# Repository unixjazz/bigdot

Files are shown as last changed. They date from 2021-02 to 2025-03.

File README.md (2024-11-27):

# librelab::Big Dot

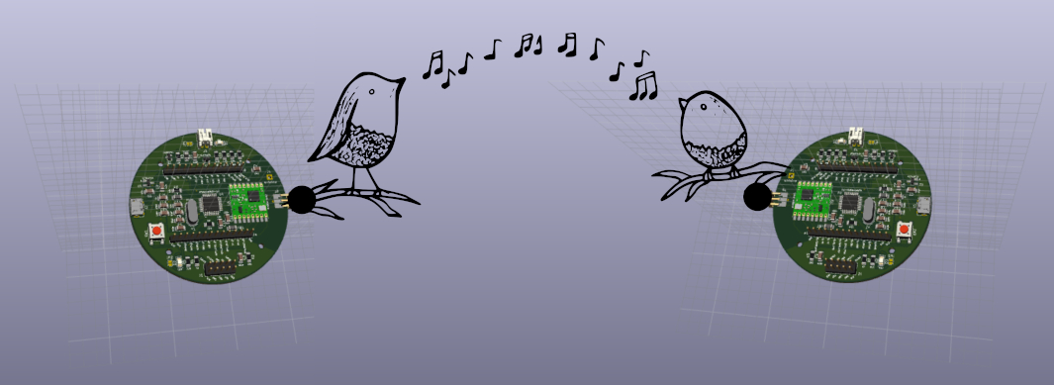
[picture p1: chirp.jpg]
These birds are chirping (CSS) with LoRa!


> A SAML21-based board kit for your environmental sensing projects!

## Description

In this repository you will find the design and firmware files for librelab::Big Dot, our libre hardware kit for low-energy LoRa applications. The content in this repo is organized in the following way:

```bash
├── arduino-core (support files)
├── board (main board design)
├── board-ext (extension board design)
├── bootloader (firmware files)
├── docs (user documentation)
└── examples (applications)
```

## Installation

### Arduino support

To install the support files for librelab::Big Dot on Arduino, just include the following line in the field 'Additional Boards Manager URL' (under 'Preferences' menu) of your Arduino IDE:

```
https://unixjazz.org/pub/software/package_librelab_index.json
```

We are using the Arduino SAMD core (v1.6), but forked and modified by [MattairTech to add support for the chip SAML21](https://github.com/mattairtech/ArduinoCore-samd). You will need Arduino 1.8.13 or superior to use this core with our board.

This core has been tested on Linux (64-bit), Windows 10, and Mac OS 10.15 (64-bit only). If you need further instructions on how to install the Arduino core, [follow this link](https://www.arduino.cc/en/guide/cores).

### RIOT-OS support

If Arduino is not suitable for your project, you can use better alternatives. All the paths lead to the same destination (when it comes to our finitude as species), but some are more direct than others. You may want to use RIOT-OS! [Our board is supported and the support can be found here](https://github.com/unixjazz/RIOT).

To use RIOT-OS with librelab::Big Dot, just pass its name to `make`:

```bash
$ BOARD=bigdot make all
```

If you are new to RIOT-OS, make sure to follow the [tutorials](https://github.com/RIOT-OS/Tutorials).

## Prototyping

If you do not have a Big Dot at hand, you can use a SAML21 Xplained board for testing purposes. The information on how to flash the bootloader we use can be found in the [bootloader directory](bootloader/README.md). For your convenience, we also included pre-compiled firmware files in this repository as well.

We recommend the usage of the UF2 bootloader included in the `bootloaders` directory: `bigdot-uf2.bin`.

## Project info

Big Dot was developed at librelab, School of Data Science (UVA) with funding from the "Network Public Spaces" (NPS) project between 2020-2021. Since then, it has been run as an independent project by Open Hardware enthusiasts.

## License

All the documentation is released as CC-BY-4.0-International.
All the hardware code is released under CERN-OHL-v2 Strongly Reciprocal.
All software code is released under GPL v3, unless marked otherwise on the source file headers. See LICENSE and AUTHORS files for further information.

Big Dot is Open Source Hardware-certified.

big-dot-cert-oshw

__Happy hw hacking!__

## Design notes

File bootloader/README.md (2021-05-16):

# SAML21 Prototyping Notes

In this document, we describe the steps for setting up the SAML21 Xplained Pro dev board for testing purposes.

## Bootloader Installation

We must use a set of tools for writing the bootloader and firmware files to the SAML21 for prototyping purposes. Here are the steps to get it up and running:

**Dependencies**

- OpenOCD v.0.10.0 or superior
- [GCC-arm-none-eabi-7-2017-q4-major](https://developer.arm.com/tools-and-software/open-source-software/developer-tools/gnu-toolchain/gnu-rm/downloads) (this is also included in the Arduino SAMD core with support for Big Dot, installable through the Arduino IDE "Boards Manager")
- [BOSSA](https://github.com/shumatech/BOSSA/releases)
- Debian 10 (or any other distro) w/ extra packages: 'libwxgtk3.0-dev' and 'libreadline-dev'

### Building the Bootloader

*Note: there are precompiled binaries included in the `bootloader` directory*

We need to build the bootloader for our board and our specific target MCU. Change to the directory `bootloader/ArduinoCore-samd-1.6.18-beta-b1/bootloaders/zero` and type:

```
$ BOARD_ID=XPLAINED_SAML21 MCU=SAML21J18B make all mostly_clean
```

After a few moments, you will have the bootloader (8K) with USB terminal support ready in the file `sam_ba_XPLAINED_SAML21_SAML21J18B.bin`.

## Bootloader alternatives

For your convenience, we built 3 different bootloaders:

* 'bigdot.bin': the standard arduino bootloader for the SAM platform
* 'bigdot-uf2.bin': the UF2 alternative bootloader w/ USB mass storage support (our choice!)
* 'sam_ba_XPLAINED_SAML21_SAML21J18B.bin': the standard arduino bootloader for the XPLAINED_SAML21 board 

Our example below uses the bootloader for the XPLAINED dev board, but you should use the 'bigdot' alternatives above if you are prototyping with librelab::Big Dot. All the bootloader files mentioned above can be found under the directory 'bootloaders'.

### Runing OpenOCD

#### Using Atmel EDBG

Plug the USB cable on the 'debug USB' port and run OpenOCD w/ the configuration file included in the `openocd-conf` directory.

```
$ openocd -f openocd-SAML21.cfg
```
If everything goes as planned, you will see this output:

```
cortex_m reset_config sysresetreq
Info : CMSIS-DAP: SWD  Supported
Info : CMSIS-DAP: Interface Initialised (SWD)
Info : CMSIS-DAP: FW Version = 03.25.01B6
Info : SWCLK/TCK = 1 SWDIO/TMS = 1 TDI = 1 TDO = 1 nTRST = 0 nRESET = 1
Info : CMSIS-DAP: Interface ready
Info : clock speed 400 kHz
Info : SWD DPIDR 0x0bc11477
Info : at91saml21j18.cpu: hardware has 4 breakpoints, 2 watchpoints
```

Do not close this terminal or exit out of OpenOCD for the next steps. 

#### Using ATMEL-ICE

If you are privileged enough to have an ATMEL ICE programmer, you can use it to program the bootloader on a brand new chip. 

Please note that you can also use any STM32F103 that you might have laying around... 
In any case, here is how to do it with the super expensive programmer!

First, ensure the 'target chip' is set properly to match your chip in the `openocd-ATMEL-ICE.cfg` file.

```T
# target chip
set CHIPNAME at91saml21j18
source [find target/at91samdXX.cfg]
```

 Plug your programmer's SAM port to the "Cortex Debug" header of your board. Then, power your board via the target USB port with and run:

```
$ openocd -f openocd-ATMEL-ICE.cfg
```

This is the output you will see on your console:

```
Info : Listening on port 6666 for tcl connections
Info : Listening on port 4444 for telnet connections
Info : CMSIS-DAP: SWD  Supported
Info : CMSIS-DAP: JTAG Supported
Info : CMSIS-DAP: FW Version = 01.00.0021
Info : CMSIS-DAP: Serial# = J42700024764
Info : CMSIS-DAP: Interface Initialised (SWD)
Info : SWCLK/TCK = 1 SWDIO/TMS = 1 TDI = 1 TDO = 1 nTRST = 0 nRESET = 1
Info : CMSIS-DAP: Interface ready
Info : clock speed 400 kHz
Info : SWD DPIDR 0x0bc11477
Info : at91saml21j18.cpu: hardware has 4 breakpoints, 2 watchpoints
Info : starting gdb server for at91saml21j18.cpu on 3333
Info : Listening on port 3333 for gdb connections
```

Do not close this terminal or exit out of OpenOCD for the next steps.

### Write Bootloader

If you are dealing with a new chip, you will have to write the bootloader and set the fuses to protect it w/ OpenOCD. First connect to the chip:

```
$ telnet 0 4444 
```
Now you can write the bootloader:

```
reset halt
at91samd bootloader 0
program sam_ba_Generic_x21J_SAML21J18B.bin verify
at91samd bootloader 8192	# this command is optional, recommended to prevent BOSSA from erasing bootloader
reset
shutdown
```
The precompiled bootloader image for the SAML21J18B was obtained from the Mattair's repository. You can find more information on how to compile the bootloader image from the documentation of his fork.

If everything goes well, you are now ready to write your programs using the Arduino core framework to the target (SAML21). This is the output of a successful verification:

```
** Programming Started **
auto erase enabled
Info : SAMD MCU: SAML21J18B (256KB Flash, 32KB RAM)
wrote 16384 bytes from file /home/unixjazz/code/SAML21-xplained-board/bootloader-arduino/sam_ba_Generic_x21J_SAML21J18B.bin in 3.540651s (4.519 KiB/s)
** Programming Finished **
** Verify Started **
verified 4964 bytes in 0.181510s (26.707 KiB/s)
** Verified OK **
** Resetting Target **
```

You should verify if everything is fine by checking if the board is properly enumerated by running

```
# dmesg
```

This should return the following output:

```
usb 3-1.2: New USB device found, idVendor=0000, idProduct=0000, bcdDevice= 2.00
usb 3-1.2: New USB device strings: Mfr=1, Product=2, SerialNumber=0
cdc_acm 3-1.2:1.0: ttyACM0: USB ACM device
```

Voilà! Toolchain and programmer are now ready for embedded fun to start.

### Flash Your Firmware

You are now ready to upload an Arduino sketch (such as `usb-term-test.bin` under the `sketches` directory) to test the USB terminal.

If you plug your board using the 'target USB' port, it should enumerate and you should have access to it. Now, you can use any tool to program your device using the USB port. You can use any sketch that makes use of USB output to test.

## Using BOSSA

Once you have the bootloader installed, you can use the `bossa` GUI utility or the `bossac` command-line utility to flash firmware onto the chip.

### Compile BOSSA

Just run `make` and `make install` to get it all ready. The binaries will be on the folder 'bin/' (`bossa`: GUI, and `bossac`: command-line tool).

### Flashing the Sample Firmware

First, test that the bootloader is successfully installed by attempting to flash the demo firmware:

```
$ bossac -e -w -v -o 8192 -b usb-term-test.bin
```

If it is successful, then you should get the following message:

```
Erase flash

Done in 0.901 seconds
Write 11856 bytes to flash (186 pages)
[==============================] 100% (186/186 pages)
Done in 0.068 seconds
Verify 11856 bytes of flash
[==============================] 100% (186/186 pages)
Verify successful
Done in 0.096 seconds
Set boot flash true
```

If you get the message

```
Device unsupported
```

and the device is properly enumerated, then press the reset button twice to enter bootloader mode.

To test to see if the sample firmware is working correctly, first open a terminal and run:

```
$ screen /dev/ttyACM0
```

Or use your favorite serial monitor, which we assume is 'screen'.

__Happy hw hacking!__

-- Sign-off: LFRM, 02/18/2021

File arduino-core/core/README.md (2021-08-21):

# librelab::Big Dot

Big Dot is a SAML21-based board targeted for low-power applications. It
was designed as an SMD kit, meant to be soldered by hand with a small
number of components.

For more information, see LICENSE and AUTHORS in the `board/` directory.
Credits for this Arduino core and its SAML21 extensions are described
below.
 
## License and Credits

This core has been developed by Arduino LLC in collaboration with Atmel.
The support for SAML21 was developed by Justin Mattair of MattairTech LLC.

```
  Copyright (c) 2015 Arduino LLC.  All right reserved.
  Copyright (c) 2017-2018 MattairTech LLC. All right reserved.

  This library is free software; you can redistribute it and/or
  modify it under the terms of the GNU Lesser General Public
  License as published by the Free Software Foundation; either
  version 2.1 of the License, or (at your option) any later version.

  This library is distributed in the hope that it will be useful,
  but WITHOUT ANY WARRANTY; without even the implied warranty of
  MERCHANTABILITY or FITNESS FOR A PARTICULAR PURPOSE.
  See the GNU Lesser General Public License for more details.

  You should have received a copy of the GNU Lesser General Public
  License along with this library; if not, write to the Free Software
  Foundation, Inc., 51 Franklin St, Fifth Floor, Boston, MA  02110-1301  USA

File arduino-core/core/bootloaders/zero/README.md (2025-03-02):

# Arduino Zero Bootloader

This bootloader is based on the Arduino Zero bootloader, which is a part of the Arduino SAMD core. This version has support for the SAML21 microcontroller, written by Justin Mattair.

## Features

* SAM-BA USB CDC and UART interfaces with optional terminal mode
* Arduino IDE auto-reset and double-tap reset button support
* Arduino extended commands for faster firmware loading
* Bossac command line utility for Linux and OS X

## License

Copyright (c) 2015 Arduino LLC.  All right reserved.
Copyright (c) 2015 Atmel Corporation/Thibaut VIARD.  All right reserved.
Copyright (c) 2017 MattairTech LLC. All right reserved.

This library is free software; you can redistribute it and/or
modify it under the terms of the GNU Lesser General Public
License as published by the Free Software Foundation; either
version 2.1 of the License, or (at your option) any later version.

This library is distributed in the hope that it will be useful,
but WITHOUT ANY WARRANTY; without even the implied warranty of
MERCHANTABILITY or FITNESS FOR A PARTICULAR PURPOSE.
See the GNU Lesser General Public License for more details.

You should have received a copy of the GNU Lesser General Public
License along with this library; if not, write to the Free Software
Foundation, Inc., 51 Franklin St, Fifth Floor, Boston, MA  02110-1301  USA

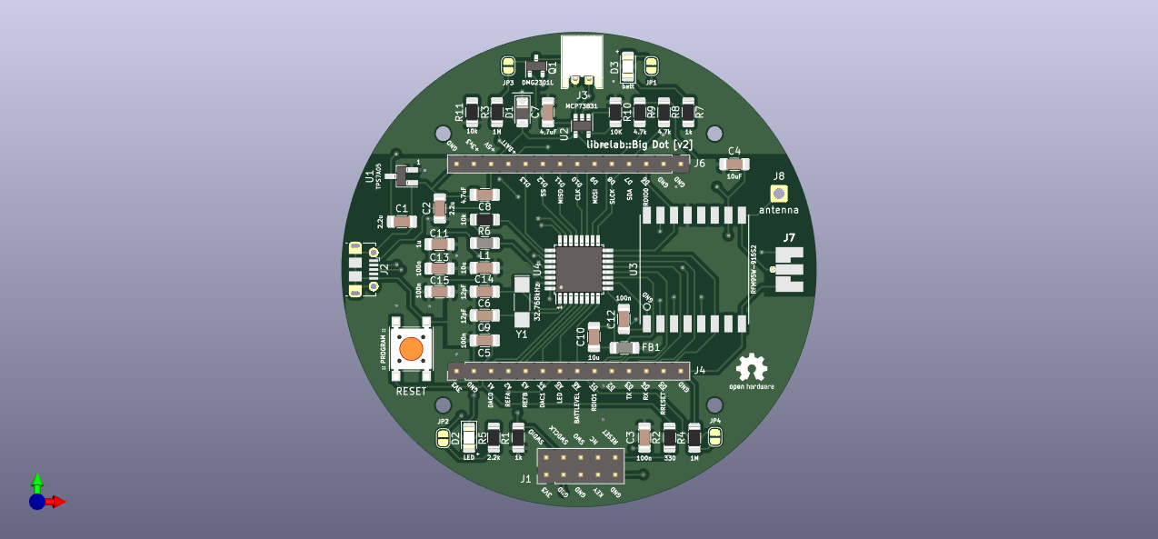
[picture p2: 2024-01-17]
board/bigdot.png

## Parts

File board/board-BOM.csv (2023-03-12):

Source: | /home/unixjazz/code/hardware/bigdot/board/board.sch |  |  |  | TPS7A0533PDBZR | TPS7A0533PDBZR
Date: | Sat 03 Jul 2021 04:25:41 PM EDT
Tool: | Eeschema 5.1.9+dfsg1-1~bpo10+1
Generator: | /usr/share/kicad/plugins/bom_csv_grouped_by_value.py
Components total | 44
SMD pads total | 146
SMD pads front | 141
SMD pads back | 5
TH pads | 45
Item | Qty | Reference(s) | Value | Datasheet | Description | Manufacturer_part_number
1 | 3 | C1, C10, C14 | 10u | ~ | CAP CER 10UF 10V X7R 1206 | C1206C106K8RAC7210
2 | 1 | C2 | 2.2u | ~ | CAP CER 2.2UF 10V X7R 1206 | C1206C225K8RACAUTO
3 | 5 | C3, C5, C12, C13, C15 | 100n | ~ | CAP CER 0.1UF 10V X7R 1206 | C1206C104K8RAC7800
4 | 3 | C4, C7, C8 | 10uF | ~ | CAP CER 10UF 10V X7R 1206 | C1206C106K8RAC7210
5 | 2 | C6, C9 | 12pF NPO | ~ | CAP CER 12PF 50V C0G/NPO 1206 | CC1206JRNPO9BN120
6 | 1 | C11 | 1u | ~ | CAP CER 1UF 10V X7R 1206 | C1206C105K8RAC7800
7 | 1 | D1 | D_Schottky | https://www.diodes.com/assets/Datasheets/ds13002.pdf | DIODE SCHOTTKY 20V 1A SOD123FL | MBR120VLSFT3GOSCT-ND
8 | 1 | D2 | LED | ~ | GREEN LED 1206 SMD
 | 1 | D3 | LED | ~ | RED LED 1206 SMD
9 | 1 | FB1 | FBMH3216HM221NT | https://ds.yuden.co.jp/TYCOMPAS/ut/detail?pn=FBMH3216HM221NT%20&u=M | FERRITE BEAD 220 OHM 1206 1LN | FBMH3216HM221NT
10 | 1 | J1 | Conn_ARM_JTAG_SWD_10 | https://media.digikey.com/pdf/Data%20Sheets/Sullins%20PDFs/Female_Headers.100_DS.pdf | Conn_ARM_JTAG_SWD_10 | PPPC052LFBN-RC
11 | 1 | J2 | USB_B_Micro | https://www.hirose.com/product/document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 | CONN RCPT USB2.0 MICRO B SMD R/A | ZX62D-B-5P8(30)
12 | 1 | J3 | Conn_01x02 | https://www.jst-mfg.com/product/pdf/eng/ePH.pdf | CONN HEADER R/A 2POS 2MM | S2B-PH-K-S(LF)(SN)
13 | 1 | J4 | Conn_01x14 | ~ | CONN HEADER 14POS -.100” [2.54 mm] Contact Centers, Female Headers,Straight/Right Angle/SMT
14 | 1 | J6 | Conn_01x14 | ~ | CONN HEADER 14POS -.100” [2.54 mm] Contact Centers, Female Headers,Straight/Right Angle/SMT
15 | 1 | J7 | Conn_Coaxial | https://www.digikey.com/en/products/detail/samtec-inc/SMA-J-P-H-ST-EM1/2602450 | CONN SMA JACK STR 50OHM EDGE MNT | SMA-J-P-H-ST-EM1
19 | 1 | L1 | 10u | https://katalog.we-online.com/pbs/datasheet/7447918.pdf | FIXED IND 10UH 25MA 600 MOHM SMD | 7447918
20 | 1 | Q1 | DMG2301L | https://www.diodes.com/assets/Datasheets/DMG2301L.pdf | MOSFET P-CH 20V 2.4A SOT23 | DMG2301LK-7
21 | 2 | R1, R7 | 1k | ~ | RES 1K OHM 1% 1/4W 1206 | RMCF1206FT1K00
22 | 1 | R2 | 330 | ~ | RES 330 OHM 1% 1/4W 1206 | RMCF1206FT330R
23 | 2 | R3, R4 | 1M | ~ | RES 1M OHM 1% 1/4W 1206 | CR1206-FX-1004ELF
24 | 1 | R5 | 2.2k | ~ | RES 2.2K OHM 1% 1/4W 1206 | RMCF1206FT2K20
25 | 2 | R6, R11 | 10k | ~ | RES 10K OHM 1% 1/4W 1206 | RMCF1206FT10K0
26 | 2 | R8, R9 | 4.7k | ~ | RES 4.7K OHM 1% 1/4W 1206 | CRG1206F4K7
27 | 1 | R10 | 2.0K | ~ | RES 2K OHM 1% 1/4W 1206 | RMCF1206FT2K00
28 | 1 | SW1 | SW_Push | https://www.ckswitches.com/media/1471/pts645.pdf | SWITCH TACTILE SPST-NO 0.05A 12V | PTS645SL50SMTR92 LFS
29 | 1 | U1 | TPS7A05 | https://www.ti.com/lit/ds/symlink/tps7a05.pdf | TPS7A0533PDBZR | TPS7A0533PDBZR
30 | 1 | U2 | MCP73831T-2ACI/OT | http://ww1.microchip.com/downloads/en/DeviceDoc/20001984g.pdf | IC BATT CNTL LI-ION 1CEL SOT23-5 | MCP73831T-2ACI/OT
31 | 1 | U3 | RFM95W-915S2 | http://www.hoperf.com/upload/rf/RFM95_96_97_98W.pdf
32 | 1 | U4 | ATSAML21E18B-AUT | http://ww1.microchip.com/downloads/en/DeviceDoc/SAM_L21_Family_DataSheet_DS60001477C.pdf | IC MCU 32BIT 256KB FLASH 32TQFP | ATSAML21E18B-AUT
33 | 1 | Y1 | 32.768kHz | https://abracon.com/Resonators/ABS10.pdf | CRYSTAL 32.7680KHZ 9PF SMD | ABS10-32.768KHZ-9-T

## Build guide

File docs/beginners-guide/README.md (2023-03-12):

# Getting Started With Arduino

**You must add the URL from the 'Arduino support section' before proceeding**

Open Arduino IDE->Tool->Board and click on Board Manager. In the search bar, type "Big Dot" then download "librelab::Big Dot by UVA SDS". Now that you have the board downloaded, to select the board go to Tools->Board->librelab::Big Dot and select Big Dot. Now Select the port, Tools->Port->(Select the port that says BigDot, i.e., "COM3 BigDot").
Now you've downloaded and selected the Big Dot!
Don't forget about the port!

**You must add the URL from the Arduino support section before you begin this section**

## Hello World!

In your Arduino IDE, select File->Examples->01.Basics and click on Blink. To upload code to BigDot, you must first press the RESET button twice. You'll know you're ready to upload code when the LED is pulsing. Once the LED is pulsing from pressing the reset button twice, click on the upload button (Arrow pointing to the right). Congrats! You should see the LED turn on and off every second.
## Required Libraries
Please download the zip files below
1. [SparkfunBME280](https://github.com/Wesleylewis05/SparkFun_BME280_Arduino_Library)
2. [U8g2lib](https://github.com/Wesleylewis05/U8g2_Arduino)
3. [PMS7003](https://github.com/Wesleylewis05/PMS)
4. [Lmic](https://github.com/Wesleylewis05/arduino-lmic)
5. [ArduinoLowPower](https://github.com/Wesleylewis05/ArduinoLowPower)
7. [RTCZero](https://github.com/Wesleylewis05/RTCZero)
7. [Adafruit Neopixel](https://github.com/Wesleylewis05/Adafruit_NeoPixel)
8. [Sam32wifiesp](https://github.com/Wesleylewis05/SAM32WiFiEsp)
9. [PubSubClient](https://github.com/Wesleylewis05/pubsubclient)
10. [AdafruitMQTT](https://github.com/Wesleylewis05/Adafruit_MQTT_Library)

Once you've downloaded everything uploads the files in your IDE. In order to use the libraries you'll have to download the zip and open Arduino IDE->Sketch->Include Library->Add .ZIP Library.

Now you're all set for using the board!

# Uploading UF2

Once you have downloaded or cloned the repository, open the "uf2_examples" directory. You should see a file named LEDPM.UF2. Now reset the board by pressing the RESET button twice. You'll know the board is reset once you see the LED next to the reset button pulse. After you've reset the board, you'll now be able to drag LEDPM.UF2 into the BigDot folder.
UF2_visualize

# Using the AdafruitIO Dashboard

To display the information from the BigDot, I will teach you how to get started using the free version of AdafruitIO. You can read more about the dashboard [here](https://io.adafruit.com/). For this, you'll need a Wifi extension board, so if you don't have that, you'll have to make some changes to the code we provide, as an example. In this tutorial, I will go over how to get started. For more information, use this [link](https://learn.adafruit.com/welcome-to-adafruit-io).

1. Create an account with Adafruit [here](https://accounts.adafruit.com/users/sign_up).

2. Go to https://io.adafruit.com/ and you should see something like below

<p align="center">
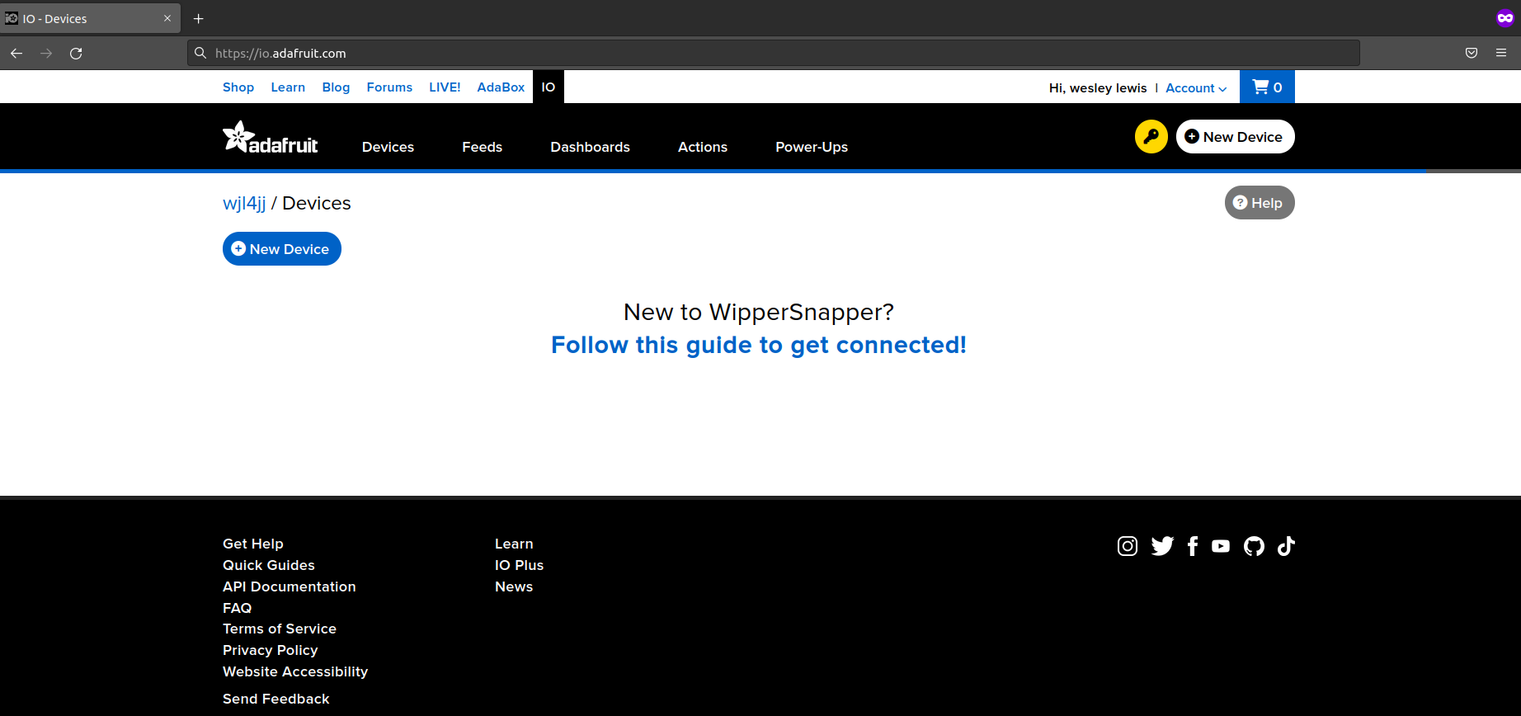
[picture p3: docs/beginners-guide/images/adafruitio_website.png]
adafruitio_website

</p>

3. Click on "Dashboards" then click on "New Dashboard" and give it a name and description. (For this example I'm going to name it "PM2_5") You should see something like the below image. If you do click on your new dashboard

<p align="center">
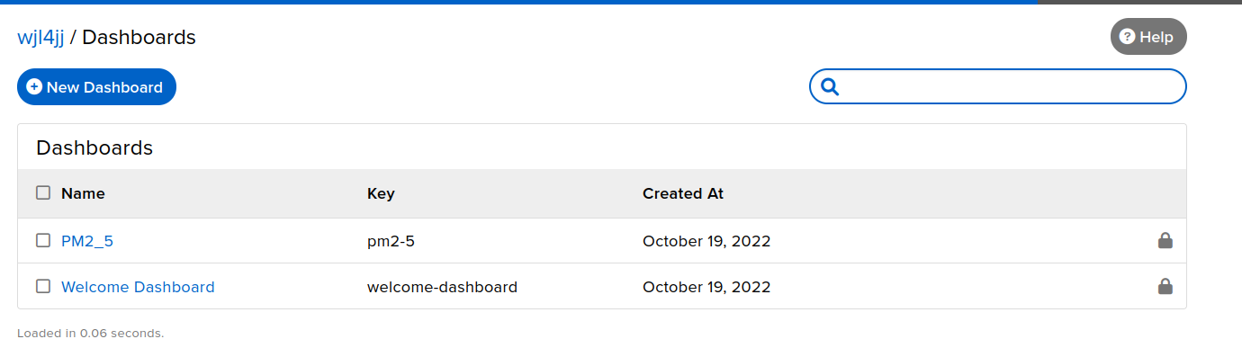
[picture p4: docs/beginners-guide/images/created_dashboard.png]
created_dashboard

</p>

4. Click on the gear icon in the upper right corner and click on "Create New Block", then click on "Line Chart"

5. Enter a feed name (I'm using "PM2_5"). Then click on create **you might have to hover your mouse right of the text box to see the create button.** Now select your new feed and click "Next Step." You can copy the settings I used in the image below.

<p align="center">
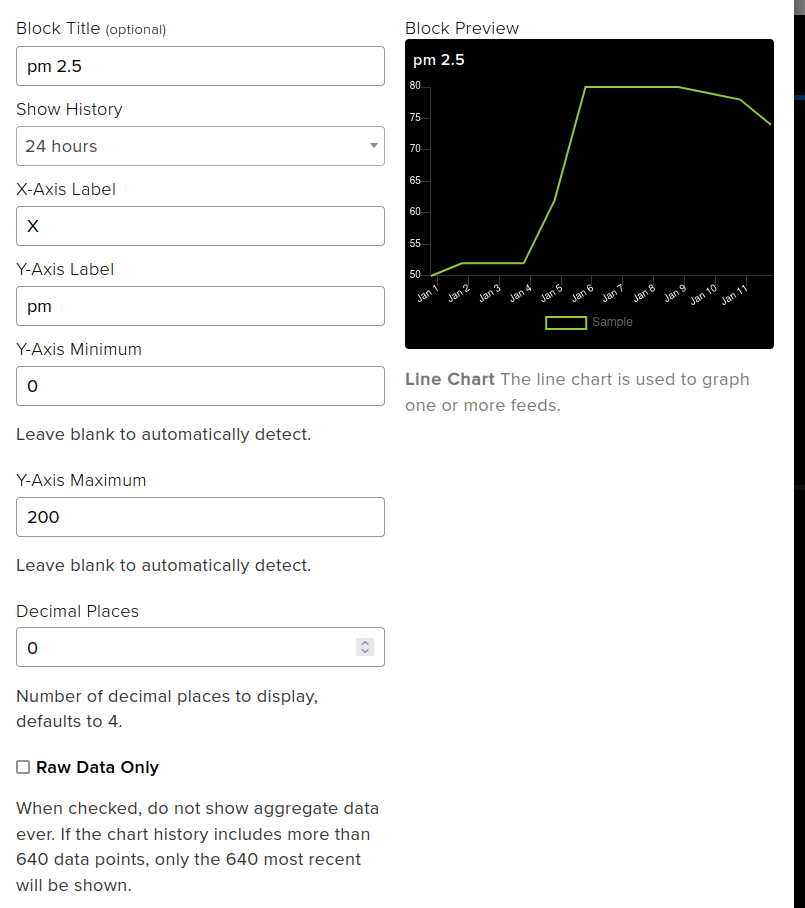
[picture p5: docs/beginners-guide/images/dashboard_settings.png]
dashboard_settings

</p>

6. Once you're finished click on the yellow key in the upper right corner and copy that username and active key somewhere. **You'll need it later.**

<p align="center">
yellow_key
</p>

<p align="center">
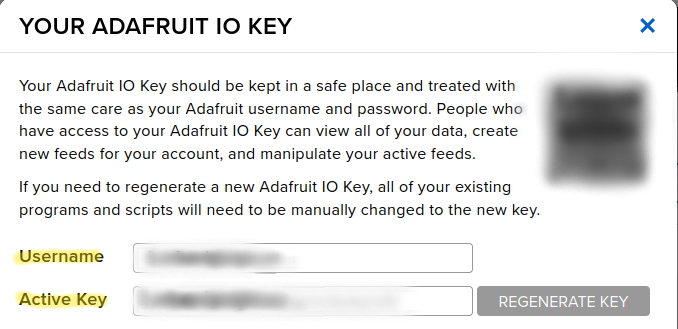
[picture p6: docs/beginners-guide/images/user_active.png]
user_active

</p>

7. Now open up the pms-wifi example from the repository using Arduino. Once it's open, scroll down until you see the Feeds section. Replace the word "TEMP" with your feed name. In this example since I'm using the feed named "PM2_5" I'll replace that with such.

<p align="center">
example_replaced_temp
</p>

8. Go to private_settings.h and replace AIO_USERNAME with the username you just copied down and AIO_KEY with the active key you copied down. Then change the WLAN_SSID name to the name of your network and WLAN_PASS to the password of the network you want to use.

9. You should now be able to upload the code! Congrats!

**Don't forget to reset the board and select the correct port!**

<p align="center">
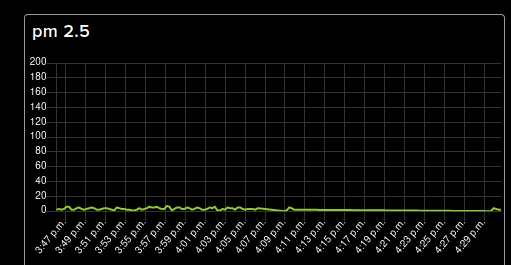
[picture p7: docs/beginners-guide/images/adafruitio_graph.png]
adafruitio_graph

</p>

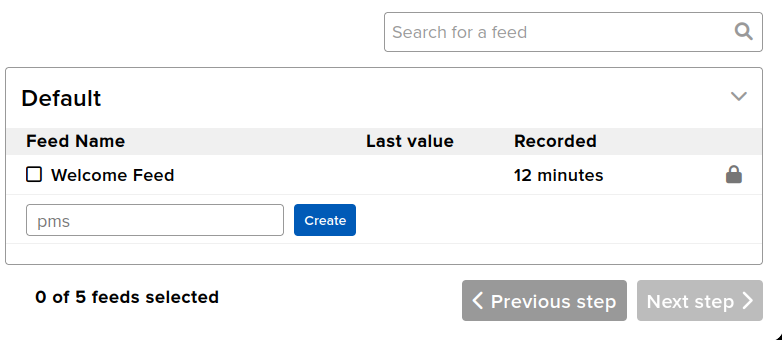
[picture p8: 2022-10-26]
docs/beginners-guide/images/new_feed.png

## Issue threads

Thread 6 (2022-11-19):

add GND plane on the extension board

unixjazz, 2022-11-19:
Hi,

The extension board was made in a rush... it does not contain a GND plane.
Turns out, that is slower and less environmentally friendly to fabricate!

So, this issue is a request for us to add a GND to the extension board and release a new PCB version.

Closed 2023-03-12.

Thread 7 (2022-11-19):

replace LDO on the Big Dot PCB

unixjazz, 2022-11-19:
During the pandemic many parts went out of stock and many got discontinued! Turns out, this is the case of our low power voltage regulator on the Big Dot project.

It is necessary to find a replacement part for U1 and substitute it, releasing a new version of the PCB once it has been tested.

unixjazz, 2022-11-29:
one substitute part would be this new one:
https://ww1.microchip.com/downloads/en/DeviceDoc/MCP1700-Data-Sheet-20001826F.pdf

it is not as energy efficient as the part we originally had, but still...

unixjazz, 2023-03-12:
thank you @Wesleylewis05!  we merged your changes in #11 for v2.

Closed 2023-03-12.

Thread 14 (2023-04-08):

Arduino IDE, v2.0 support

unixjazz, 2023-04-08:
The new version of the Arduino IDE (v2.0) seems to be causing trouble for extension packages for various boards and architectures. This is the case of SAMD (such as Seeed's XIAO) and SAML boards (ours).  We can continue using v1.8.x until Arduino v2.0 is stable, but we must plan for the upgrade soon.

unixjazz, 2023-04-29:
update on this issue:
tested against Arduino IDE v.2.1: custom board package can be installed without problems

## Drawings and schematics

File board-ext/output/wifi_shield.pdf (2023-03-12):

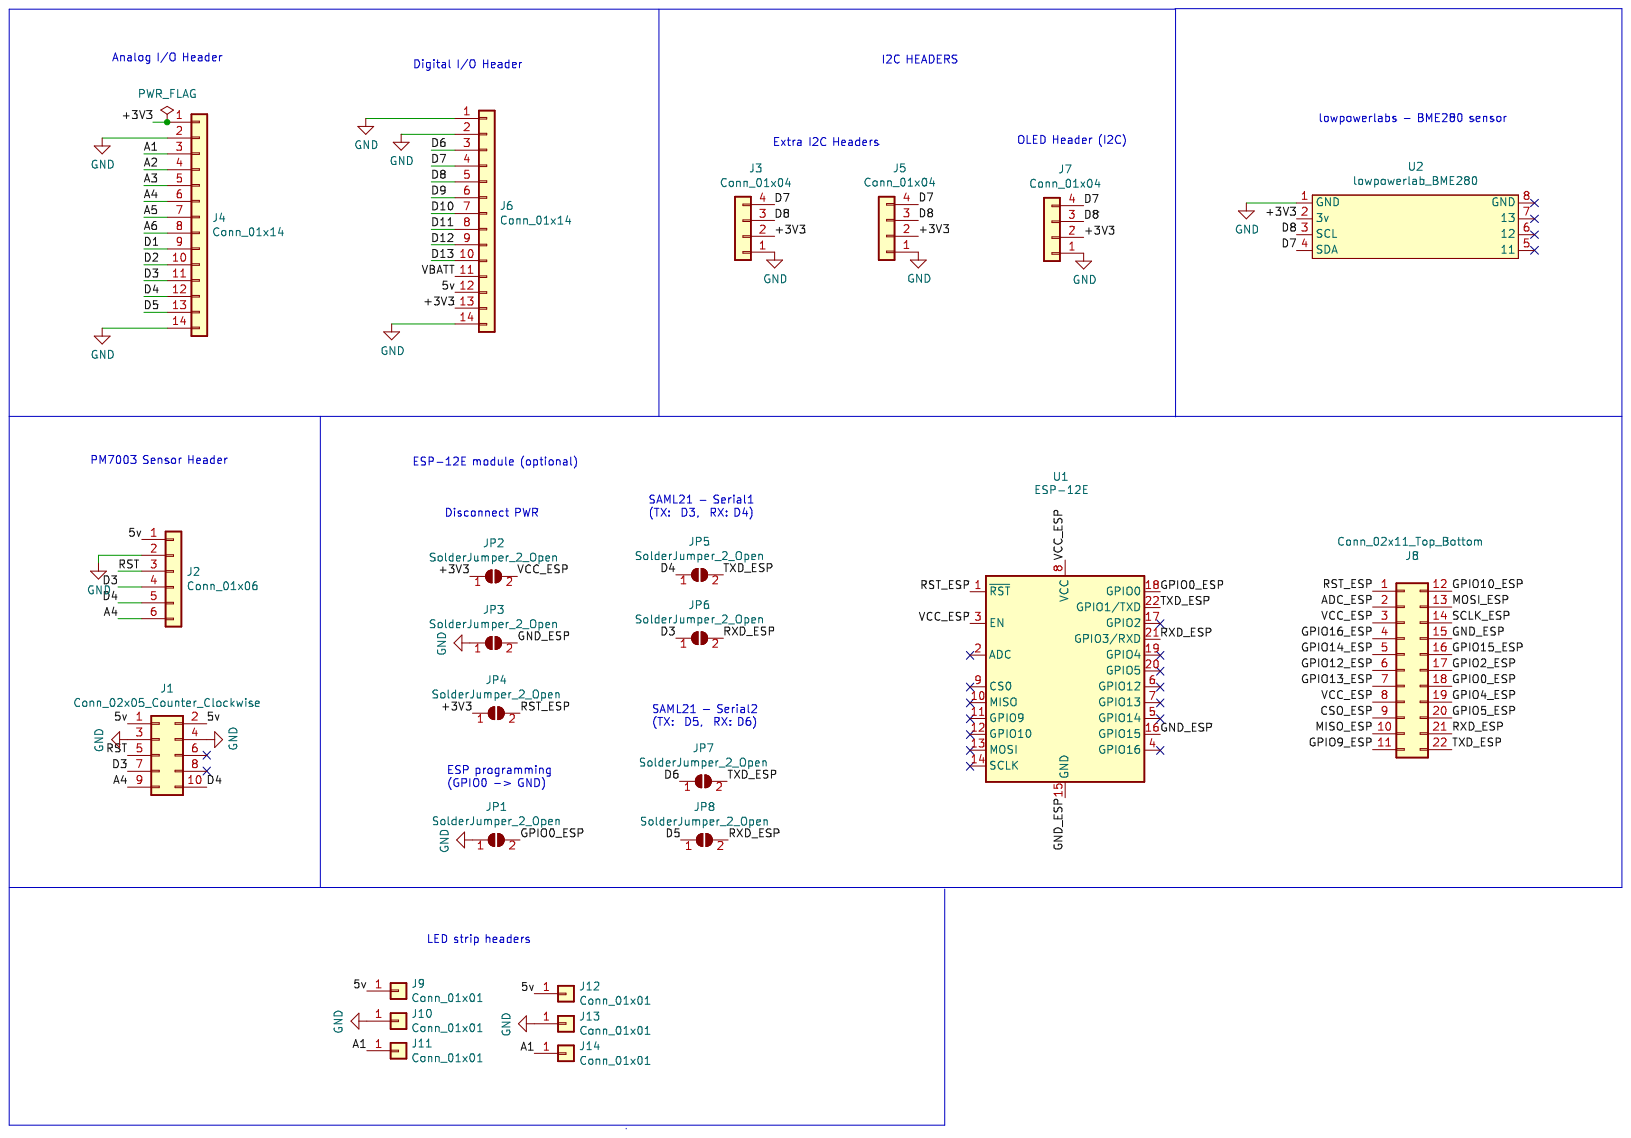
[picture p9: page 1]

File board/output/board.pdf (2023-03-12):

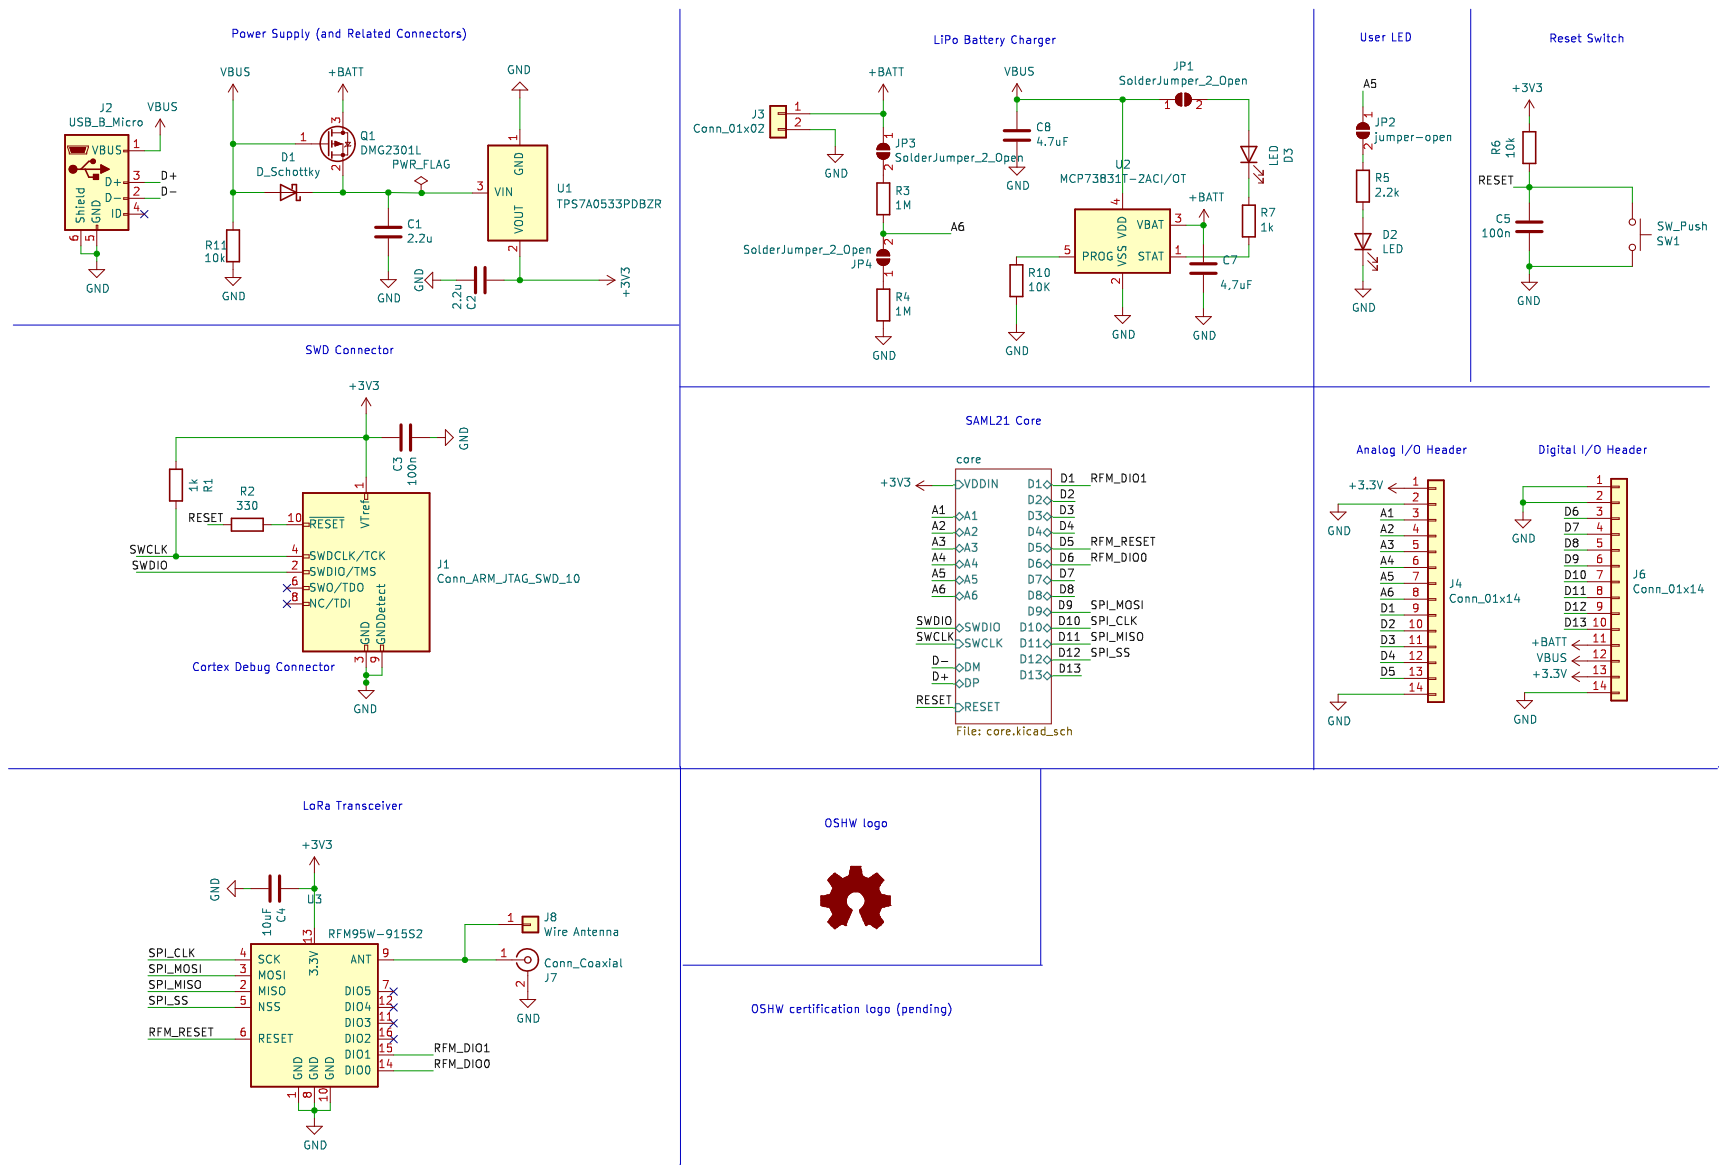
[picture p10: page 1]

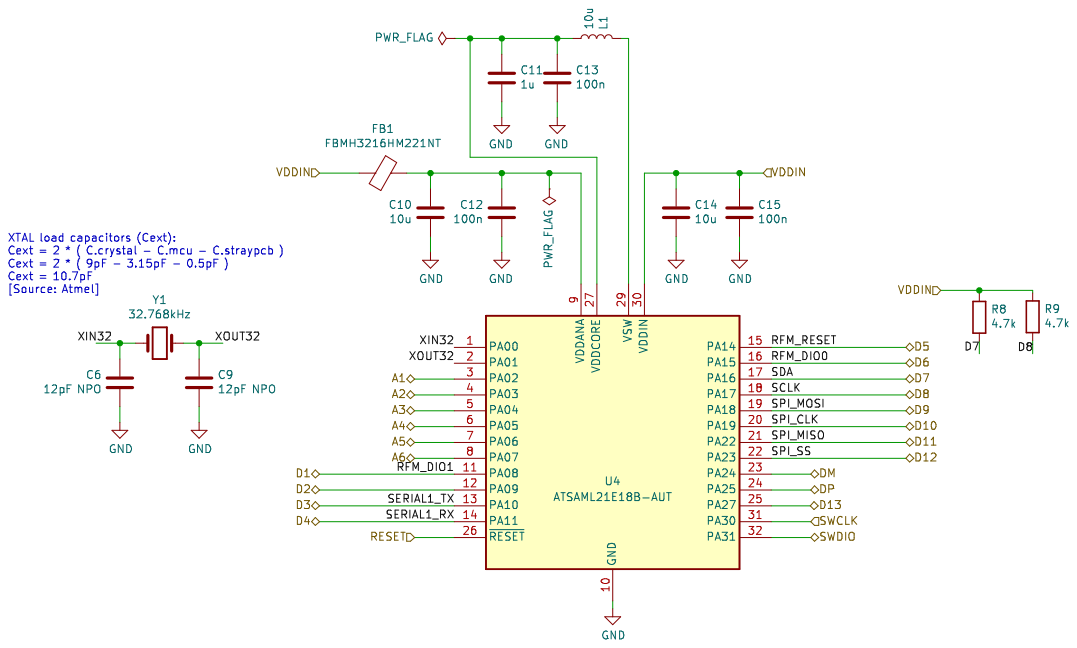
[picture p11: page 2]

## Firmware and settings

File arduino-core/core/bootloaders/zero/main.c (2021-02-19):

/*
  Copyright (c) 2015 Arduino LLC.  All right reserved.
  Copyright (c) 2015 Atmel Corporation/Thibaut VIARD.  All right reserved.

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
  You should have received a copy of the GNU Lesser General Public
  License along with this library; if not, write to the Free Software
  Foundation, Inc., 51 Franklin St, Fifth Floor, Boston, MA  02110-1301  USA
*/

#include <stdio.h>
#include <stdbool.h>
#include <sam.h>
#include "sam_ba_monitor.h"
#include "sam_ba_serial.h"
#include "board_definitions.h"
#include "board_driver_led.h"
#include "util.h"
#if (SAMD21 || SAMD11 || SAML21 || SAMD51)
  #include "sam_ba_usb.h"
  #include "sam_ba_cdc.h"
#endif

extern uint32_t __sketch_vectors_ptr; // Exported value from linker script
extern volatile int8_t ledDirection;
extern void board_init(void);

#if (defined DEBUG) && (DEBUG == 1)
volatile uint32_t* pulSketch_Start_Address;
#endif

static volatile bool main_b_cdc_enable = false;

/**
 * \brief Check the application startup condition
 *
 */
static void check_start_application(void)
{
#if (!defined DEBUG) || ((defined DEBUG) && (DEBUG == 0))
uint32_t* pulSketch_Start_Address;
#endif

  /*
   * Test sketch stack pointer @ &__sketch_vectors_ptr
   * Stay in SAM-BA if value @ (&__sketch_vectors_ptr) == 0xFFFFFFFF (Erased flash cell value)
   */
  if (__sketch_vectors_ptr == 0xFFFFFFFF)
  {
    /* Stay in bootloader */
    return;
  }

  /*
   * Load the sketch Reset Handler address
   * __sketch_vectors_ptr is exported from linker script and point on first 32b word of sketch vector table
   * Remember, variables exported from a linker script are different than normal variables (only address, no value)
   * First 32b word is sketch stack
   * Second 32b word is sketch entry point: Reset_Handler()
   */
  pulSketch_Start_Address = &__sketch_vectors_ptr ;
  pulSketch_Start_Address++ ;

  /*
   * Test vector table address of sketch @ &__sketch_vectors_ptr
   * Stay in SAM-BA if this function is not aligned enough, ie not valid
   */
  if ( ((uint32_t)(&__sketch_vectors_ptr) & ~SCB_VTOR_TBLOFF_Msk) != 0x00)
  {
    /* Stay in bootloader */
    return;
  }

#if defined(BOOT_LOAD_PIN_ENABLED)
  pinConfig(BOOT_LOAD_PIN_PORT, BOOT_LOAD_PIN, BOOT_LOAD_PIN_CONFIG);

  /* Allow time for debouncing capacitor (if using a button) to charge (10ms) */
  delayUs(10000UL);

  // Read the BOOT_LOAD_PIN status
  if (isPinActive(BOOT_LOAD_PIN_PORT, BOOT_LOAD_PIN, BOOT_LOAD_PIN_POLARITY))
  {
    // Stay in bootloader
    return;
  }
#endif

#if defined(BOOT_DOUBLE_TAP_ENABLED)
  #define DOUBLE_TAP_MAGIC 0x07738135

#if (SAMD21 || SAMD11)
  if (PM->RCAUSE.bit.POR)
#elif (SAML21 || SAMC21 || SAMD51)
  if (RSTC->RCAUSE.bit.POR)
#else
  #error "main.c: Missing dependency or unsupported chip. Please install CMSIS-Atmel from MattairTech (see Prerequisites for Building in README.md)."
#endif

  {
    /* On power-on initialize double-tap */
    BOOT_DOUBLE_TAP_DATA = 0;
  }
  else
  {
    if (BOOT_DOUBLE_TAP_DATA == DOUBLE_TAP_MAGIC)
    {
      /* Second tap, stay in bootloader */
      BOOT_DOUBLE_TAP_DATA = 0;
      return;
    }

    /* First tap */
    BOOT_DOUBLE_TAP_DATA = DOUBLE_TAP_MAGIC;

    /* Wait 0.5sec to see if the user tap reset again */
    delayUs(500000UL);

    /* Timeout happened, continue boot... */
    BOOT_DOUBLE_TAP_DATA = 0;
  }
#endif

  /* Rebase the Stack Pointer */
  __set_MSP( (uint32_t)(__sketch_vectors_ptr) );

  /* Rebase the vector table base address */
  SCB->VTOR = ((uint32_t)(&__sketch_vectors_ptr) & SCB_VTOR_TBLOFF_Msk);

  /* Jump to application Reset Handler in the application */
  asm("bx %0"::"r"(*pulSketch_Start_Address));
}

#if DEBUG_ENABLE
#	define DEBUG_PIN_HIGH 	port_pin_set_output_level(BOOT_LED, 1)
#	define DEBUG_PIN_LOW 	port_pin_set_output_level(BOOT_LED, 0)
#else
#	define DEBUG_PIN_HIGH 	do{}while(0)
#	define DEBUG_PIN_LOW 	do{}while(0)
#endif

/**
 *  \brief SAMD21 SAM-BA Main loop.
 *  \return Unused (ANSI-C compatibility).
 */
int main(void)
{
#if SAM_BA_INTERFACE == SAM_BA_USBCDC_ONLY  ||  SAM_BA_INTERFACE == SAM_BA_BOTH_INTERFACES
  P_USB_CDC pCdc;
#endif
  DEBUG_PIN_HIGH;

  /* Jump in application if condition is satisfied */
  check_start_application();

  /* We have determined we should stay in the monitor. */

  /* System initialization */
  board_init();
  __enable_irq();

  /* Initialize LEDs */
  LED_init();
  #if !defined(BOARD_LED_FADE_ENABLED)
  LED_on();
  #endif
  LEDRX_init();
  LEDRX_off();
  LEDTX_init();
  LEDTX_off();

  /* Start the sys tick (20 us) */
  SysTick_Config(VARIANT_MCK / 50000);


/* When using SAM_BA_INTERFACE_USE_PIN, check the pin to determine which SAM-BA interface to use.
 */
#if defined(SAM_BA_INTERFACE_USE_PIN)
  uint8_t sambaInterface = SAM_BA_NONE;
  pinConfig(SAM_BA_INTERFACE_PIN_PORT, SAM_BA_INTERFACE_PIN_PIN, SAM_BA_INTERFACE_PIN_CONFIG);

  if (isPinActive(SAM_BA_INTERFACE_PIN_PORT, SAM_BA_INTERFACE_PIN_PIN, PIN_POLARITY_ACTIVE_LOW)) {      // pin is low
  #if ((SAM_BA_INTERFACE == SAM_BA_BOTH_INTERFACES) && (SAM_BA_INTERFACE_PIN_POLARITY == PIN_POLARITY_USBCDC_LOW))
    sambaInterface = SAM_BA_USBCDC_ONLY;
  #elif ((SAM_BA_INTERFACE == SAM_BA_USBCDC_ONLY) && (SAM_BA_INTERFACE_PIN_POLARITY == PIN_POLARITY_ACTIVE_LOW))
    sambaInterface = SAM_BA_USBCDC_ONLY;
  #elif ((SAM_BA_INTERFACE == SAM_BA_UART_ONLY) && (SAM_BA_INTERFACE_PIN_POLARITY == PIN_POLARITY_ACTIVE_LOW))
    sambaInterface = SAM_BA_UART_ONLY;
  #endif
  } else {      // pin is high
  #if ((SAM_BA_INTERFACE == SAM_BA_BOTH_INTERFACES) && (SAM_BA_INTERFACE_PIN_POLARITY == PIN_POLARITY_USBCDC_HIGH))
    sambaInterface = SAM_BA_USBCDC_ONLY;
  #elif ((SAM_BA_INTERFACE == SAM_BA_USBCDC_ONLY) && (SAM_BA_INTERFACE_PIN_POLARITY == PIN_POLARITY_ACTIVE_HIGH))
    sambaInterface = SAM_BA_USBCDC_ONLY;
  #elif ((SAM_BA_INTERFACE == SAM_BA_UART_ONLY) && (SAM_BA_INTERFACE_PIN_POLARITY == PIN_POLARITY_ACTIVE_HIGH))
    sambaInterface = SAM_BA_UART_ONLY;
  #endif
  }
#endif

/* Check if we should continue with a SAM-BA interface (if compiled and enabled).
 * Only show LED_STATUS_FILE_NOT_FOUND if a SAM-BA interface is not available.
 * LED_STATUS_FILE_NOT_FOUND occurs if there is no SD Card, no FAT16/FAT32
 * filesystem, or no file (UPDATE.BIN or UPDATE2.BIN) in the root directory.
 */
#if defined(SAM_BA_INTERFACE_USE_PIN)
  #if defined(SDCARD_ENABLED)
  if (sambaInterface == SAM_BA_NONE) {
    if (sdcardStatus == SD_BOOTLOADER_FILE_NOT_FOUND) {
      LED_status(LED_STATUS_FILE_NOT_FOUND);
    } else if (sdcardStatus == SD_BOOTLOADER_NOT_CALLED) {
      LED_status(LED_STATUS_NO_SAM_BA_INTERFACE);
    }
  }
  #else
    #if (SAM_BA_INTERFACE == SAM_BA_NONE)
      LED_status(LED_STATUS_NO_SAM_BA_INTERFACE);
    #else
    if (sambaInterface == SAM_BA_NONE) {
      LED_status(LED_STATUS_NO_SAM_BA_INTERFACE);
    }
    #endif
  #endif
#else
  #if (SAM_BA_INTERFACE == SAM_BA_NONE)
    LED_status(LED_STATUS_NO_SAM_BA_INTERFACE);
  #endif
#endif

/* Enable the appropriate SAM-BA interfaces. When using SAM_BA_INTERFACE_USE_PIN,
 * the peripheral and pins are only setup for the selected/enabled interface.
 */
#if defined(SAM_BA_INTERFACE_USE_PIN)
  if (sambaInterface == SAM_BA_UART_ONLY) {
#endif

#if SAM_BA_INTERFACE == SAM_BA_UART_ONLY  ||  SAM_BA_INTERFACE == SAM_BA_BOTH_INTERFACES
  /* UART is enabled in all cases */
    serial_open();
#endif

#if defined(SAM_BA_INTERFACE_USE_PIN)
  } else if (sambaInterface == SAM_BA_USBCDC_ONLY) {
#endif

#if SAM_BA_INTERFACE == SAM_BA_USBCDC_ONLY  ||  SAM_BA_INTERFACE == SAM_BA_BOTH_INTERFACES
    pCdc = usb_init();
#endif

#if defined(SAM_BA_INTERFACE_USE_PIN)
  }
#endif


  ledDirection = 4;
  DEBUG_PIN_LOW;

  /* Wait for a complete enum on usb or a '#' char on serial line */
  while (1)
  {
#if defined(SAM_BA_INTERFACE_USE_PIN)
    if (sambaInterface == SAM_BA_USBCDC_ONLY) {
#endif

#if SAM_BA_INTERFACE == SAM_BA_USBCDC_ONLY  ||  SAM_BA_INTERFACE == SAM_BA_BOTH_INTERFACES
    if (pCdc->IsConfigured(pCdc) != 0)
    {
      main_b_cdc_enable = true;
    }

    /* Check if a USB enumeration has succeeded and if comm port has been opened */
    if (main_b_cdc_enable)
    {
      sam_ba_monitor_init(SAM_BA_INTERFACE_USBCDC);
      /* SAM-BA on USB loop */
      while( 1 )
      {
        sam_ba_monitor_run();
      }
    }
#endif

#if defined(SAM_BA_INTERFACE_USE_PIN)
    } else if (sambaInterface == SAM_BA_UART_ONLY) {
#endif

#if SAM_BA_INTERFACE == SAM_BA_UART_ONLY  ||  SAM_BA_INTERFACE == SAM_BA_BOTH_INTERFACES
    /* Check if a '#' has been received */
    if (!main_b_cdc_enable && serial_sharp_received())
    {
      sam_ba_monitor_init(SAM_BA_INTERFACE_USART);
      /* SAM-BA on Serial loop */
      while(1)
      {
        sam_ba_monitor_run();
      }
    }
#endif

#if defined(SAM_BA_INTERFACE_USE_PIN)
    }
#endif
  }
}

void SysTick_Handler(void)
{
#if (defined(BOARD_LED_FADE_ENABLED) && defined(BOARD_LED_PORT))
  LED_pulse();
#endif

  sam_ba_monitor_sys_tick();
}

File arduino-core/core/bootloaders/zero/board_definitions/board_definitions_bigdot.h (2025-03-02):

/*
  Copyright (c) 2020 Librelab. All right reserved.
  Copyright (c) 2017 MattairTech LLC. All right reserved.
  Copyright (c) 2015 Arduino LLC.  All right reserved.
  Copyright (c) 2015 Atmel Corporation/Thibaut VIARD.  All right reserved.

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
  You should have received a copy of the GNU Lesser General Public
  License along with this library; if not, write to the Free Software
  Foundation, Inc., 51 Franklin St, Fifth Floor, Boston, MA  02110-1301  USA
*/

#ifndef _BOARD_DEFINITIONS_H_
#define _BOARD_DEFINITIONS_H_

#include <sam.h>

/* The SAM-BA interface, which is used with both USB CDC and UART (TTL
 * serial), can operate in either binary (default) or terminal mode. If
 * TERMINAL_MODE_ENABLED is defined, additional terminal handling code
 * (add prompt, add \n\r to EOL, number formatting, etc.) will be compiled
 * in. To switch to terminal mode, type 'T#' (you should then see a prompt).
 * Then, type 'V#' to show version information. See README.md for more commands.
 * Size: ~228B. Enabled by default. Disable with 4KB bootloader.
 */
//#define TERMINAL_MODE_ENABLED

/* Set SAM_BA_INTERFACE to SAM_BA_USBCDC_ONLY, SAM_BA_UART_ONLY, SAM_BA_NONE, or
 * SAM_BA_BOTH_INTERFACES. With 4KB bootloaders, select only one interface (except
 * when using SDCARD_ENABLED, then set SAM_BA_INTERFACE to SAM_BA_NONE).
 */
#define SAM_BA_INTERFACE	SAM_BA_USBCDC_ONLY

/* If ARDUINO_EXTENDED_CAPABILITIES is defined and set to 1, 3 additional commands
 * will become available which will speed up programming when using the Arduino
 * IDE or the bossac tool standalone. Set to 0 with 4KB bootloaders.
 * Size: ~904B. This is defined and set to 1 by default (except with 4KB).
 */
#define ARDUINO_EXTENDED_CAPABILITIES	1

/* The clock source must be chosen by setting CLOCKCONFIG_CLOCK_SOURCE to
 * CLOCKCONFIG_32768HZ_CRYSTAL, CLOCKCONFIG_HS_CRYSTAL, CLOCKCONFIG_INTERNAL,
 * or CLOCKCONFIG_INTERNAL_USB. If CLOCKCONFIG_32768HZ_CRYSTAL or
 * CLOCKCONFIG_HS_CRYSTAL is defined, then the PLL will be used. If
 * CLOCKCONFIG_HS_CRYSTAL is defined, then HS_CRYSTAL_FREQUENCY_HERTZ must
 * also be defined with the crystal frequency in Hertz. CLOCKCONFIG_INTERNAL
 * uses the DFLL in open-loop mode, except with the C21 which lacks a DFLL, so
 * the internal 48MHz RC oscillator is used instead. CLOCKCONFIG_INTERNAL_USB
 * can be defined for the D21, D11, L21, or D51. It will also use the DFLL in
 * open-loop mode, except when connected to a USB port with data lines (and
 * not suspended), where it will calibrate against the USB SOF signal.
 */
#ifndef CLOCKCONFIG_CLOCK_SOURCE
  #define CLOCKCONFIG_CLOCK_SOURCE	CLOCKCONFIG_32768HZ_CRYSTAL
#endif

/* If CLOCKCONFIG_HS_CRYSTAL is defined, then HS_CRYSTAL_FREQUENCY_HERTZ
 * must also be defined with the external crystal frequency in Hertz.
 */
#define HS_CRYSTAL_FREQUENCY_HERTZ	16000000UL

/* If the PLL is used (CLOCKCONFIG_32768HZ_CRYSTAL, or CLOCKCONFIG_HS_CRYSTAL
 * defined), then PLL_FRACTIONAL_ENABLED can be defined, which will result in
 * a more accurate 48MHz output frequency at the expense of increased jitter.
 */
#define PLL_FRACTIONAL_ENABLED

/* If both PLL_FAST_STARTUP and CLOCKCONFIG_HS_CRYSTAL are defined, the crystal
 * will be divided down to 1MHz - 2MHz, rather than 32KHz - 64KHz, before being
 * multiplied by the PLL. This will result in a faster lock time for the PLL,
 * however, it will also result in a less accurate PLL output frequency if the
 * crystal is not divisible (without remainder) by 1MHz. In this case, define
 * PLL_FRACTIONAL_ENABLED as well.
 */
//#define PLL_FAST_STARTUP

/* Master clock frequency (also Fcpu frequency). */
#define VARIANT_MCK	(48000000ul)

/* The fine calibration value for DFLL open-loop mode is defined here.
 * The coarse calibration value is loaded from NVM OTP (factory calibration values).
 */
#define NVM_SW_CALIB_DFLL48M_FINE_VAL     (512)

/* If USB_VENDOR_STRINGS_ENABLED is defined, then STRING_MANUFACTURER and
 * STRING_PRODUCT will be sent to the host.
 * Size: ~228B. By default, USB_VENDOR_STRINGS_ENABLED is defined (including 4KB).
 */
#define USB_VENDOR_STRINGS_ENABLED
#define STRING_MANUFACTURER "librelab"
#define STRING_PRODUCT "Big Dot"

/* If USB CDC is used, then the USB vendor ID (VID) and product ID (PID) must be set. */
#define USB_VID_HIGH   0x12
#define USB_VID_LOW    0x09
#define USB_PID_HIGH   0xBD
#define USB_PID_LOW    0x00
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

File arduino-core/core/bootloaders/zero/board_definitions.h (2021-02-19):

/*
  Copyright (c) 2015 Arduino LLC.  All right reserved.
  Copyright (c) 2015 Atmel Corporation/Thibaut VIARD.  All right reserved.
  Copyright (c) 2017 MattairTech LLC. All right reserved.

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
  You should have received a copy of the GNU Lesser General Public
  License along with this library; if not, write to the Free Software
  Foundation, Inc., 51 Franklin St, Fifth Floor, Boston, MA  02110-1301  USA
*/

#include <sam.h>
#include "board_definitions/board_definitions_bigdot.h"

// Common definitions
// ------------------

// These are undefined in CMSIS for L21, C21, and D51
#if (SAML21)
#ifndef GCLK_CLKCTRL_ID_SERCOM0_CORE_Val
  #define GCLK_CLKCTRL_ID_SERCOM0_CORE_Val	18
  #define GCLK_CLKCTRL_ID_SERCOM1_CORE_Val	19
  #define GCLK_CLKCTRL_ID_SERCOM2_CORE_Val	20
  #define GCLK_CLKCTRL_ID_SERCOM3_CORE_Val	21
  #define GCLK_CLKCTRL_ID_SERCOM4_CORE_Val	22
  #define GCLK_CLKCTRL_ID_SERCOM5_CORE_Val	24
#endif
#endif

#define LED_POLARITY_LOW_ON             0
#define LED_POLARITY_HIGH_ON            1
#define PIN_POLARITY_ACTIVE_LOW         0
#define PIN_POLARITY_ACTIVE_HIGH        1
#define PIN_POLARITY_USBCDC_LOW         0
#define PIN_POLARITY_USBCDC_HIGH        1

#define INPUT                   (0x0)
#define OUTPUT                  (0x1)
#define INPUT_PULLUP            (0x2)
#define INPUT_PULLDOWN          (0x3)
#define OUTPUT_HIGH             (0x4)
#define OUTPUT_LOW              (0x5)

#define PINMUX_UNUSED          0xFFFFFFFF

/*
 * If BOOT_DOUBLE_TAP_ENABLED is defined the bootloader is started by
 * quickly tapping two times on the reset button.
 * BOOT_DOUBLE_TAP_ADDRESS must point to a free SRAM cell that must not
 * be touched from the loaded application. By default, the SRAM
 * location is the last 4 bytes.
 */
#if (SAMD21 || SAMD11)
  #define BOOT_DOUBLE_TAP_ADDRESS           (HMCRAMC0_ADDR + HMCRAMC0_SIZE - 4)
#elif (SAML21 || SAMC21 || SAMD51)
  #define BOOT_DOUBLE_TAP_ADDRESS           (HSRAM_ADDR + HSRAM_SIZE - 4)
#else
  #error "board_definitions.h: Missing dependency or unsupported chip. Please install CMSIS-Atmel from MattairTech (see Prerequisites for Building in README.md)."
#endif

#define BOOT_DOUBLE_TAP_DATA              (*((volatile uint32_t *) BOOT_DOUBLE_TAP_ADDRESS))

#if (BOOT_USART_SERCOM_INSTANCE == 0)
  #define BOOT_USART_MODULE                   SERCOM0
  #define BOOT_USART_PER_CLOCK_INDEX          GCLK_CLKCTRL_ID_SERCOM0_CORE_Val
  #if (SAMD21 || SAMD11)
    #define BOOT_USART_BUS_CLOCK_INDEX        PM_APBCMASK_SERCOM0
  #elif (SAML21 || SAMC21)
    #define BOOT_USART_BUS_CLOCK_INDEX        MCLK_APBCMASK_SERCOM0
  #elif (SAMD51)
    #define BOOT_USART_BUS_CLOCK_INDEX        MCLK_APBAMASK_SERCOM0
  #endif
#elif (BOOT_USART_SERCOM_INSTANCE == 1)
  #define BOOT_USART_MODULE                   SERCOM1
  #define BOOT_USART_PER_CLOCK_INDEX          GCLK_CLKCTRL_ID_SERCOM1_CORE_Val
  #if (SAMD21 || SAMD11)
    #define BOOT_USART_BUS_CLOCK_INDEX        PM_APBCMASK_SERCOM1
  #elif (SAML21 || SAMC21)
    #define BOOT_USART_BUS_CLOCK_INDEX        MCLK_APBCMASK_SERCOM1
  #elif (SAMD51)
    #define BOOT_USART_BUS_CLOCK_INDEX        MCLK_APBAMASK_SERCOM1
  #endif
#elif (BOOT_USART_SERCOM_INSTANCE == 2)
  #define BOOT_USART_MODULE                   SERCOM2
  #define BOOT_USART_PER_CLOCK_INDEX          GCLK_CLKCTRL_ID_SERCOM2_CORE_Val
  #if (SAMD21 || SAMD11)
    #define BOOT_USART_BUS_CLOCK_INDEX        PM_APBCMASK_SERCOM2
  #elif (SAML21 || SAMC21)
    #define BOOT_USART_BUS_CLOCK_INDEX        MCLK_APBCMASK_SERCOM2
  #elif (SAMD51)
    #define BOOT_USART_BUS_CLOCK_INDEX        MCLK_APBBMASK_SERCOM2
  #endif
#elif (BOOT_USART_SERCOM_INSTANCE == 3)
  #define BOOT_USART_MODULE                   SERCOM3
  #define BOOT_USART_PER_CLOCK_INDEX          GCLK_CLKCTRL_ID_SERCOM3_CORE_Val
  #if (SAMD21 || SAMD11)
    #define BOOT_USART_BUS_CLOCK_INDEX        PM_APBCMASK_SERCOM3
  #elif (SAML21 || SAMC21)
    #define BOOT_USART_BUS_CLOCK_INDEX        MCLK_APBCMASK_SERCOM3
  #elif (SAMD51)
    #define BOOT_USART_BUS_CLOCK_INDEX        MCLK_APBBMASK_SERCOM3
  #endif
#elif (BOOT_USART_SERCOM_INSTANCE == 4)
  #define BOOT_USART_MODULE                   SERCOM4
  #define BOOT_USART_PER_CLOCK_INDEX          GCLK_CLKCTRL_ID_SERCOM4_CORE_Val
  #if (SAMD21 || SAMD11)
    #define BOOT_USART_BUS_CLOCK_INDEX        PM_APBCMASK_SERCOM4
  #elif (SAML21 || SAMC21)
    #define BOOT_USART_BUS_CLOCK_INDEX        MCLK_APBCMASK_SERCOM4
  #elif (SAMD51)
    #define BOOT_USART_BUS_CLOCK_INDEX        MCLK_APBDMASK_SERCOM4
  #endif
#elif (BOOT_USART_SERCOM_INSTANCE == 5)
  #define BOOT_USART_MODULE                   SERCOM5
  #define BOOT_USART_PER_CLOCK_INDEX          GCLK_CLKCTRL_ID_SERCOM5_CORE_Val
  #if (SAMD21 || SAMD11)
    #define BOOT_USART_BUS_CLOCK_INDEX        PM_APBCMASK_SERCOM5
  #elif (SAML21 || SAMC21)
    #define BOOT_USART_BUS_CLOCK_INDEX        MCLK_APBCMASK_SERCOM5
  #elif (SAMD51)
    #define BOOT_USART_BUS_CLOCK_INDEX        MCLK_APBDMASK_SERCOM5
  #endif
#elif (BOOT_USART_SERCOM_INSTANCE == 6)
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

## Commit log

2021-02-19 first commit.
    [SAML21E18B.cfg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]
2021-03-20 added registered USB VID/PID numbers to the core and firmware.
2021-03-23 Changes to the board to prepare for RC1
    - Added pull-down R (10k)
    - Changed XTAL (ABS10)
    - Changed values for load caps (C7-9) for XTAL
    - Changed PROG value for batt controller (2k)
    - Updated pin headers to include 3v3 and RFM_DIO1 pins
    - Added jumpers to disable voltage divider (1M) on pin A6
    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
    [board-B_Cu.gbl, board-B_Mask.gbs, board-B_Paste.gbp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]
2021-04-15 Modified boards.txt
2021-06-29 initial work on wifi shield
    [wifi_shield.kicad_pcb, wifi_shield.sch]
2021-07-03 Pending fixes on rc1:
    - added 10u cap for batt controller
    - fixed poor connections on schematic, missed traces on D1 and C7
    - changed RFMDIO1 pin to D1 (fixes issues w/ LoRa downlink)
    - realigned components, repositioned traces
    - increased pad sizes for hand-solderability on Q1 and U2
    - overall retracing and re-alignment of components
    Sign-off: LFRM, 07-03-2021
    [board-BOM.csv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]
2021-08-21 increased ground plane, increased small IC pad sizes for hand soldering.
    [board-B_Cu.gbl, board-B_Mask.gbs, board-B_Paste.gbp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]
2021-08-21 released 1.1.0: using XTAL by default; reorganized Arduino core dir; adjusted versioning.
    [SAML21E18B.cfg]
2021-09-15 added WiFi extension board, v1.
    [wifi_shield-B_Cu.gbl, wifi_shield-B_Mask.gbs, wifi_shield-B_Paste.gbp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]
2021-09-16 added fw code for the extension board to be used w/ LoRa.
2021-10-23 Added silkscreening to extension board
    [wifi_shield.kicad_pcb]
2021-10-26 updated to v.1.1: fixed alignment and silkscreen labels, swapped pins A4 and RX on J1.
    [wifi_shield-B_Cu.gbl, wifi_shield-B_Mask.gbs, wifi_shield-B_Paste.gbp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]
2021-10-27 fixed C1 value for LDO stabilization (2.2uF), adjusted current charge PROG (10K, 100mA), reverted values for C7 and C8 (4.7uF).
    [board-B_Cu.gbl, board-B_Mask.gbs, board-B_Paste.gbp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]
2021-11-05 version v1.2: ESP GPIO15 pulled down, updated silkscreen, repositioned PMS headers.
    [wifi_shield-B_Cu.gbl, wifi_shield-B_Mask.gbs, wifi_shield-B_Paste.gbp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]
2021-11-09 added example with Serial2 for extra sensor.
2021-11-09 Example code for ext-board with WiFi chip
    Example code for ext-board with WiFi chip
2021-11-19 added example for Datapalooza workshop: PM2.5, PM10, temp, humidity, pressure over LoRa.
2023-03-11 updated silkscreen version on wifi shield to v1.3.
    [wifi_shield.kicad_pcb, wifi_shield.kicad_sch]
2023-03-12 upgraded design files to KiCad v6.
    [board.kicad_pcb, board.kicad_sch, board.sch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]
2023-03-12 updated main board design files to KiCad 7.
    [board.kicad_pcb, board.kicad_sch, core.kicad_sch]
2023-03-12 updated LDO to TPS7A0533PDBZR. added ic pdfs
    [board-BOM.csv, board.kicad_pcb, board.kicad_sch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]
2023-03-12 renamed datasheet folder, exported Gerber files, updated silkscreen to v2.
    [board-B_Cu.gbl, board-B_Mask.gbs, board-B_Paste.gbp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]
2023-03-12 updated gerb, drill, and pdf in output
    [board-B_Cu.gbl, board-B_Mask.gbs, board-B_Paste.gbp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]
2023-03-12 updated design files to kicad7, added GND plane for ext-board v1.3.
    [wifi_shield-B_Cu.gbl, wifi_shield-B_Mask.gbs, wifi_shield-B_Paste.gbp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]
2023-03-12 updated gerb, drill, and pdf for extension board
    [wifi_shield-B_Cu.gbl, wifi_shield-B_Mask.gbs, wifi_shield-B_Paste.gbp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]
2023-03-12 fix for board/AUTHORS merge conflict
2024-01-17 added cert logo, updated files to v2 release.
    [board.kicad_sch, core.kicad_sch]
2024-11-26 added very-low-power define to board init.
2024-11-27 added support for Arduino IDE v2.
2025-03-02 removed local config file for kicad.
